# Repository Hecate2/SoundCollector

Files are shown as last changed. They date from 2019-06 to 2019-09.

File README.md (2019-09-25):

# SoundCollector
录音电路。这是一个课程项目，需要±12V和+5V同时供电，因此没有实用价值。该电路用OP07CP做两级反向放大器和一级加法器。
用IAP15F2K61S2单片机采样，并用串口发送至电脑。
保存数据为bin文件后，用MATLAB播放。有两阶RC无源低通滤波（虽然这一步并没有实际意义）。
受限于串口的传输速率（最高波特率115200），无法保留高频的成分。

我已经用实际硬件调试成功。用MATLAB运行play.m即可播放sound.bin录音结果。
需要STC公司的软件stc-isp-15xx-v6.86q.exe来烧录单片机程序。其中的串口助手还可收取串口传来的录音数据。

stcmcu_altium_lib.IntLib由STC制作，含STC各种单片机的原理图，封装，footprint，用于Altium Designer设计PCB。

Mic.PrjPcb是实际电路图的PCB设计项目。最终采用的PCB设计是Mic2.PcbDoc。这个板子的纵向高度正好能装进淘宝上的8格塑料盒子，横向宽度也可以再缩一缩。可变电阻用VR5封装，可调节放大倍数和加法器。**原理图Mic.SchDoc把OP07CP的+12V和-12V供电画反了，但PCB上标注的+12V和-12V是正确的。**MAX232CPE和串口端可以用USB转串口的单片机编程器代替。淘宝上不到十块钱，可靠性绝佳。退耦电容C99，C100，C101完全可以不焊，反正是专门的直流电源和电脑主板供电。**电容C0的电压是下面比上面高（或者说靠近单片机的一侧电压比较高）。千万不要焊反了。**
MicOP07CP.ms14是模拟电路的仿真。可用Multisim 14打开。

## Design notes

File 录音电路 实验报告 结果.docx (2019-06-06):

6、 实验结果
  a) 不播放音乐时的模拟输出

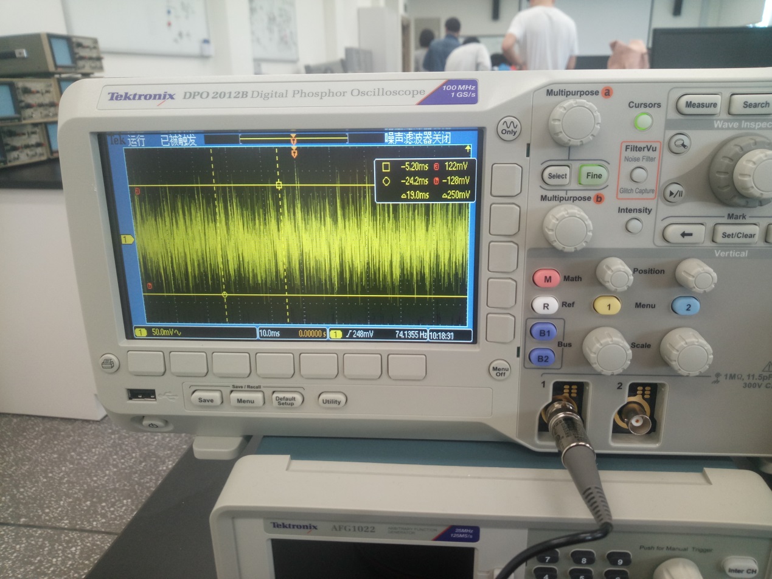
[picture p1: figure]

进行这一试验是为了测试模拟输出的底噪。测试环境并没有完全静音。可认为底噪幅度小于128mV。

  b) 模拟音频信噪比

假设模拟音频平均幅值2V，则信噪比大于10log10((2/0.128)²)= 23.8764 dB

  c) 录音结果（已经数字化）

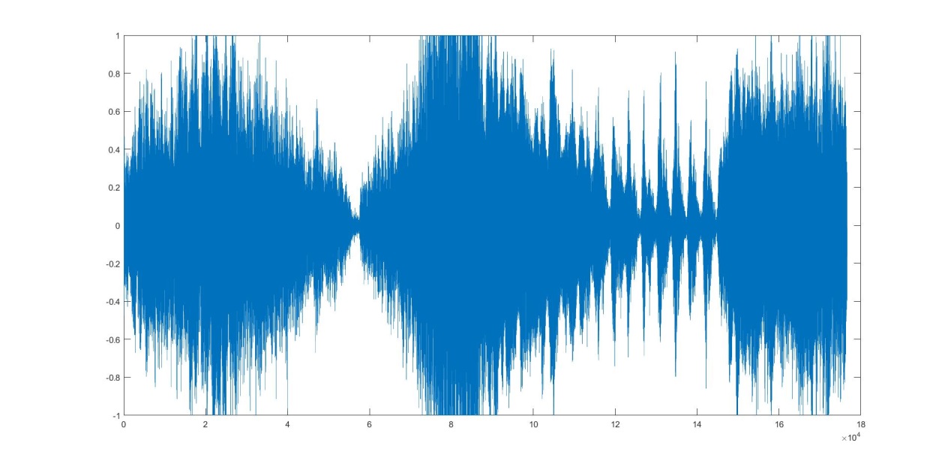
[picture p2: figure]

由于播放音乐音量过大，电压有时会超出采样范围。可调节放大倍数阻止这一现象。

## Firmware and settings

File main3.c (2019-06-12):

#include <stc15fxxxx.h> //调用stc15f系列头文件,下载地址: http://pan.baidu.com/s/1eRUbjLS

//串口部分-----------------------------------------------------------------------------------------------------------------------------------------------------------------------------------

/*************常量定义****************/


#define MAIN_Fosc 22118400L //主时钟,晶振频率不同的直接在这里修改频率
#define serial_one_read_max 32 //定义缓存区的长度
#define serial_one_baud_rate 115200L //波特率,只需在这里修改波特率就可以了
#define Timer1_Reload (65536UL -(MAIN_Fosc / 4 / serial_one_baud_rate))  //用定时器1做波特率发生器，计算定时器1的重装值 


/*************变量定义****************/
u8 serial_one_read_data[serial_one_read_max]; //定义串口接受数据缓存区
u8 serial_one_read_count=0; //接受数据的个数


//初始化串口1
void serial_one_init()
{
SCON |= 0x40; //8位数据
P_SW1 &= ~0xc0; //UART1 使用P30 P31口 默认
TR1 = 0; //关闭定时器
AUXR &= ~0x01; //S1 BRT Use Timer1;
TMOD &= ~(1<<6); //Timer1 set As Timer
TMOD &= ~0x30; //Timer1_16bitAutoReload;2
AUXR |= (1<<6); //Timer1 set as 1T mode
TH1 = (u8)(Timer1_Reload >> 8);
TL1 = (u8)Timer1_Reload;
TR1 = 1; //打开定时器
PS = 1; //高优先级中断
REN = 1; //允许接收
ES = 1; //允许中断


EA = 1; //允许全局中断
}


//延时10毫秒
void Delay10ms() //@22.1184MHz
{
unsigned char i, j, k;


_nop_();
_nop_();
i = 1;
j = 216;
k = 35;
do
{
do
{
while (--k);
} while (--j);
} while (--i);
}


//串口1发送一个字节
void serial_one_send_byte(u8 dat)
{
SBUF = dat;//发送数据
while(!TI);//等待发送完毕
TI=0; //清除发送标志
}


//串口1发送字符串
void serial_one_send_string(u8 *dat)
{
while(*dat)
serial_one_send_byte(*dat++);
}


//串口1发送指定指定长度数据
void serial_one_send_length_string(u8 *dat,u8 length)
{
u8 i=0;
for(;i < length;i++)
serial_one_send_byte(dat[i]);
}

/********************* 串口1中断函数************************/
void UART1_int (void) interrupt UART1_VECTOR
{
if(RI)
{
RI = 0;//清除接受标志
serial_one_read_data[serial_one_read_count] = SBUF;//将数据存入数组
if(++serial_one_read_count > serial_one_read_max) //避免溢出
serial_one_read_count = 0;
}


// if(TI)
// {
// }
}


//ADC部分----------------------------------------------------------------------------------------------------------------------------------------------------

//#include "reg51.h"
//#include "intrins.h"

#define FOSC    11059200L
#define BAUD    9600

typedef unsigned char BYTE;
typedef unsigned int WORD;

#define     URMD    0           //0:使用定时器2作为波特率发生器
                                //1:使用定时器1的模式0(16位自动重载模式)作为波特率发生器
                                //2:使用定时器1的模式2(8位自动重载模式)作为波特率发生器

#define ADC_POWER   0x80            //ADC电源控制位
#define ADC_FLAG    0x10            //ADC完成标志
#define ADC_START   0x08            //ADC起始控制位
#define ADC_SPEEDLL 0x00            //540个时钟
#define ADC_SPEEDL  0x20            //360个时钟
#define ADC_SPEEDH  0x40            //180个时钟
#define ADC_SPEEDHH 0x60            //90个时钟

void InitUart();
void InitADC();
void SendData(BYTE dat);
BYTE GetADCResult(BYTE ch);
void Delay(WORD n);
void ShowResult(BYTE ch);

void main()
{
    P0M0 = 0x00;
    P0M1 = 0x00;
    P1M0 = 0x00;
    P1M1 = 0x00;
    P2M0 = 0x00;
    P2M1 = 0x00;
    P3M0 = 0x00;
    P3M1 = 0x00;
    P4M0 = 0x00;
    P4M1 = 0x00;
    P5M0 = 0x00;
    P5M1 = 0x00;
    P6M0 = 0x00;
    P6M1 = 0x00;
    P7M0 = 0x00;
    P7M1 = 0x00;

Delay10ms();//延时10毫秒
Delay10ms();//延时10毫秒
serial_one_init();//串口初始化

//if(serial_one_read_count > 0)//如果接受到数据
//{
//Delay10ms();//延时10毫秒，等待数据全部读入
//serial_one_send_length_string(serial_one_read_data,serial_one_read_count);//发送接收到的数据
//serial_one_read_count = 0;//接收计数清0
//}

    InitADC();                      //初始化ADC
    while (1)
    {
        //ShowResult(0);              //显示通道0
        //ShowResult(1);              //显示通道1
        //ShowResult(2);              //显示通道2
        //ShowResult(3);              //显示通道3
        //ShowResult(4);              //显示通道4
        //ShowResult(5);              //显示通道5
        //ShowResult(6);              //显示通道6
        //ShowResult(7);              //显示通道7
			u8 dat=GetADCResult(7);
			serial_one_send_length_string(&dat,1);
    }
}

/*----------------------------
读取ADC结果
----------------------------*/
BYTE GetADCResult(BYTE ch)
{
    ADC_CONTR = ADC_POWER | ADC_SPEEDLL | ch | ADC_START;
    _nop_();                        //等待4个NOP
    _nop_();
    _nop_();
    _nop_();
    while (!(ADC_CONTR & ADC_FLAG));//等待ADC转换完成
    ADC_CONTR &= ~ADC_FLAG;         //Close ADC

    return ADC_RES;                 //返回ADC结果
}

/*----------------------------
初始化ADC
----------------------------*/
void InitADC()
{
    P1ASF = 0xff;                   //设置P1口为AD口
    ADC_RES = 0;                    //清除结果寄存器
    ADC_CONTR = ADC_POWER | ADC_SPEEDLL;
    Delay(2);                       //ADC上电并延时
}


/*----------------------------
软件延时
----------------------------*/
void Delay(WORD n)
{
    WORD x;

    while (n--)
    {
        x = 5000;
        while (x--);
    }
}

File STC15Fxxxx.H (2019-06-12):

#ifndef	_STC15Fxxxx_H
#define	_STC15Fxxxx_H

#include <intrins.h>

/*  BYTE Registers  */
sfr P0   = 0x80;
sfr SP   = 0x81;
sfr DPL  = 0x82;
sfr DPH  = 0x83;
sfr	S4CON = 0x84;
sfr	S4BUF = 0x85;
sfr PCON = 0x87;

sfr TCON = 0x88;
sfr TMOD = 0x89;
sfr TL0  = 0x8A;
sfr TL1  = 0x8B;
sfr TH0  = 0x8C;
sfr TH1  = 0x8D;
sfr	AUXR = 0x8E;
sfr WAKE_CLKO = 0x8F;
sfr INT_CLKO = 0x8F;
sfr	AUXR2    = 0x8F;

sfr RL_TL0  = 0x8A;
sfr RL_TL1  = 0x8B;
sfr RL_TH0  = 0x8C;
sfr RL_TH1  = 0x8D;


sfr P1   = 0x90;
sfr P1M1 = 0x91;	//P1M1.n,P1M0.n 	=00--->Standard,	01--->push-pull		实际上1T的都一样
sfr P1M0 = 0x92;	//					=10--->pure input,	11--->open drain
sfr P0M1 = 0x93;	//P0M1.n,P0M0.n 	=00--->Standard,	01--->push-pull
sfr P0M0 = 0x94;	//					=10--->pure input,	11--->open drain
sfr P2M1 = 0x95;	//P2M1.n,P2M0.n 	=00--->Standard,	01--->push-pull
sfr P2M0 = 0x96;	//					=10--->pure input,	11--->open drain
sfr CLK_DIV = 0x97;
sfr PCON2   = 0x97;

sfr SCON  = 0x98;
sfr SBUF  = 0x99;
sfr S2CON = 0x9A;	//
sfr S2BUF = 0x9B;	//
sfr P1ASF = 0x9D;	//只写，模拟输入(AD或LVD)选择

sfr P2    = 0xA0;
sfr BUS_SPEED = 0xA1;
sfr AUXR1 = 0xA2;
sfr P_SW1 = 0xA2;

sfr IE    = 0xA8;
sfr SADDR = 0xA9;
sfr WKTCL = 0xAA;	//唤醒定时器低字节
sfr WKTCH = 0xAB;	//唤醒定时器高字节
sfr	S3CON = 0xAC;
sfr S3BUF = 0xAD;
sfr IE2   = 0xAF;	//STC12C5A60S2系列

sfr P3    = 0xB0;
sfr P3M1  = 0xB1;	//P3M1.n,P3M0.n 	=00--->Standard,	01--->push-pull
sfr P3M0  = 0xB2;	//					=10--->pure input,	11--->open drain
sfr P4M1  = 0xB3;	//P4M1.n,P4M0.n 	=00--->Standard,	01--->push-pull
sfr P4M0  = 0xB4;	//					=10--->pure input,	11--->open drain
sfr IP2   = 0xB5;	//STC12C5A60S2系列
sfr IPH2  = 0xB6;	//STC12C5A60S2系列
sfr IPH   = 0xB7;

sfr IP        = 0xB8;
sfr SADEN     = 0xB9;
sfr	P_SW2     = 0xBA;
sfr ADC_CONTR = 0xBC;	//带AD系列
sfr ADC_RES   = 0xBD;	//带AD系列
sfr ADC_RESL  = 0xBE;	//带AD系列

sfr P4        = 0xC0;
sfr WDT_CONTR = 0xC1;
sfr IAP_DATA  = 0xC2;
sfr IAP_ADDRH = 0xC3;
sfr IAP_ADDRL = 0xC4;
sfr IAP_CMD   = 0xC5;
sfr IAP_TRIG  = 0xC6;
sfr IAP_CONTR = 0xC7;

sfr ISP_DATA  = 0xC2;
sfr ISP_ADDRH = 0xC3;
sfr ISP_ADDRL = 0xC4;
sfr ISP_CMD   = 0xC5;
sfr ISP_TRIG  = 0xC6;
sfr ISP_CONTR = 0xC7;

sfr P5     = 0xC8;	//
sfr P5M1   = 0xC9;	//	P5M1.n,P5M0.n 	=00--->Standard,	01--->push-pull
sfr P5M0   = 0xCA;	//					=10--->pure input,	11--->open drain
sfr P6M1   = 0xCB;	//	P5M1.n,P5M0.n 	=00--->Standard,	01--->push-pull
sfr P6M0   = 0xCC;	//					=10--->pure input,	11--->open drain
sfr SPSTAT = 0xCD;	//
sfr SPCTL  = 0xCE;	//
sfr SPDAT  = 0xCF;	//

sfr PSW  = 0xD0;
sfr	T4T3M = 0xD1;
sfr	T4H  = 0xD2;
sfr	T4L  = 0xD3;
sfr	T3H  = 0xD4;
sfr	T3L  = 0xD5;
sfr	T2H  = 0xD6;
sfr	T2L  = 0xD7;

sfr	TH4  = 0xD2;
sfr	TL4  = 0xD3;
sfr	TH3  = 0xD4;
sfr	TL3  = 0xD5;
sfr	TH2  = 0xD6;
sfr	TL2  = 0xD7;

sfr	RL_T4H  = 0xD2;
sfr	RL_T4L  = 0xD3;
sfr	RL_T3H  = 0xD4;
sfr	RL_T3L  = 0xD5;
sfr	RL_T2H  = 0xD6;
sfr	RL_T2L  = 0xD7;

sfr CCON = 0xD8;	//
sfr CMOD = 0xD9;	//
sfr CCAPM0 = 0xDA;	//PCA模块0的工作模式寄存器。
sfr CCAPM1 = 0xDB;	//PCA模块1的工作模式寄存器。
sfr CCAPM2 = 0xDC;	//PCA模块2的工作模式寄存器。

sfr ACC    = 0xE0;
sfr	P7M1   = 0xE1;
sfr	P7M0   = 0xE2;

sfr	P6     = 0xE8;
sfr CL     = 0xE9;	//
sfr CCAP0L = 0xEA;	//PCA模块0的捕捉/比较寄存器低8位。
sfr CCAP1L = 0xEB;	//PCA模块1的捕捉/比较寄存器低8位。
sfr CCAP2L = 0xEC;	//PCA模块2的捕捉/比较寄存器低8位。

sfr B      = 0xF0;
sfr PCA_PWM0 = 0xF2;	//PCA模块0 PWM寄存器。
sfr PCA_PWM1 = 0xF3;	//PCA模块1 PWM寄存器。
sfr PCA_PWM2 = 0xF4;	//PCA模块2 PWM寄存器。

sfr	P7     = 0xF8;
sfr CH     = 0xF9;
sfr CCAP0H = 0xFA;		//PCA模块0的捕捉/比较寄存器高8位。
sfr CCAP1H = 0xFB;		//PCA模块1的捕捉/比较寄存器高8位。
sfr CCAP2H = 0xFC;		//PCA模块2的捕捉/比较寄存器高8位。


/*  BIT Registers  */
/*  PSW   */
sbit CY   = PSW^7;
sbit AC   = PSW^6;
sbit F0   = PSW^5;
sbit RS1  = PSW^4;
sbit RS0  = PSW^3;
sbit OV   = PSW^2;
sbit F1   = PSW^1;
sbit P    = PSW^0;

/*  TCON  */
sbit TF1  = TCON^7;	//定时器1溢出中断标志位
sbit TR1  = TCON^6;	//定时器1运行控制位
sbit TF0  = TCON^5;	//定时器0溢出中断标志位
sbit TR0  = TCON^4;	//定时器0运行控制位
sbit IE1  = TCON^3;	//外中断1标志位
sbit IT1  = TCON^2;	//外中断1信号方式控制位，1：下降沿中断，0：上升下降均中断。
sbit IE0  = TCON^1;	//外中断0标志位
sbit IT0  = TCON^0;	//外中断0信号方式控制位，1：下降沿中断，0：上升下降均中断。

/*  P0  */
sbit  P00 = P0^0;
sbit  P01 = P0^1;
sbit  P02 = P0^2;
sbit  P03 = P0^3;
sbit  P04 = P0^4;
sbit  P05 = P0^5;
sbit  P06 = P0^6;
sbit  P07 = P0^7;

/*  P1  */
sbit  P10 = P1^0;
sbit  P11 = P1^1;
sbit  P12 = P1^2;
sbit  P13 = P1^3;
sbit  P14 = P1^4;
sbit  P15 = P1^5;
sbit  P16 = P1^6;
sbit  P17 = P1^7;

sbit  RXD2      = P1^0;
sbit  TXD2      = P1^1;
sbit  CCP1      = P1^0;
sbit  CCP0      = P1^1;
sbit  SPI_SS    = P1^2;
sbit  SPI_MOSI  = P1^3;
sbit  SPI_MISO  = P1^4;
sbit  SPI_SCLK  = P1^5;

sbit  SPI_SS_2    = P2^4;
sbit  SPI_MOSI_2  = P2^3;
sbit  SPI_MISO_2  = P2^2;
sbit  SPI_SCLK_2  = P2^1;

sbit  SPI_SS_3    = P5^4;
sbit  SPI_MOSI_3  = P4^0;
sbit  SPI_MISO_3  = P4^1;
sbit  SPI_SCLK_3  = P4^3;

/*  P2  */
sbit  P20 = P2^0;
sbit  P21 = P2^1;
sbit  P22 = P2^2;
sbit  P23 = P2^3;
sbit  P24 = P2^4;
sbit  P25 = P2^5;
sbit  P26 = P2^6;
sbit  P27 = P2^7;

/*  P3  */
sbit  P30 = P3^0;
sbit  P31 = P3^1;
sbit  P32 = P3^2;
sbit  P33 = P3^3;
sbit  P34 = P3^4;
sbit  P35 = P3^5;
sbit  P36 = P3^6;
sbit  P37 = P3^7;

sbit RXD  = P3^0;
sbit TXD  = P3^1;
sbit INT0 = P3^2;
sbit INT1 = P3^3;
sbit T0   = P3^4;
sbit T1   = P3^5;
sbit WR   = P3^6;
sbit RD   = P3^7;
sbit CCP2  = P3^7;

sbit CLKOUT0   = P3^5;
sbit CLKOUT1   = P3^4;

/*  P4  */
sbit  P40 = P4^0;
sbit  P41 = P4^1;
sbit  P42 = P4^2;
sbit  P43 = P4^3;
sbit  P44 = P4^4;
sbit  P45 = P4^5;
sbit  P46 = P4^6;
sbit  P47 = P4^7;

/*  P5  */
sbit  P50 = P5^0;
sbit  P51 = P5^1;
sbit  P52 = P5^2;
sbit  P53 = P5^3;
sbit  P54 = P5^4;
sbit  P55 = P5^5;
sbit  P56 = P5^6;
sbit  P57 = P5^7;

/*  SCON  */
sbit SM0  = SCON^7;	//SM0/FE		SM0 SM1 = 00 ~ 11: 方式0~3
sbit SM1  = SCON^6;	//
sbit SM2  = SCON^5;	//多机通讯
sbit REN  = SCON^4;	//接收允许
sbit TB8  = SCON^3;	//发送数据第8位
sbit RB8  = SCON^2;	//接收数据第8位
sbit TI   = SCON^1;	//发送中断标志位
sbit RI   = SCON^0;	//接收中断标志位

/*  IE   */
sbit EA   = IE^7;	//中断允许总控制位
sbit ELVD = IE^6;	//低压监测中断允许位
sbit EADC = IE^5;	//ADC 中断 允许位
sbit ES   = IE^4;	//串行中断 允许控制位
sbit ET1  = IE^3;	//定时中断1允许控制位
sbit EX1  = IE^2;	//外部中断1允许控制位
sbit ET0  = IE^1;	//定时中断0允许控制位
sbit EX0  = IE^0;	//外部中断0允许控制位


/*  IP   */ 
/*
sbit PPCA = IP^7;	//PCA 中断 优先级设定位
sbit PLVD = IP^6; 	//低压中断 优先级设定位
sbit PADC = IP^5; 	//ADC 中断 优先级设定位
sbit PS   = IP^4;	//串行中断0优先级设定位
sbit PT1  = IP^3;	//定时中断1优先级设定位
sbit PX1  = IP^2;	//外部中断1优先级设定位
sbit PT0  = IP^1;	//定时中断0优先级设定位
sbit PX0  = IP^0;	//外部中断0优先级设定位
*/

sbit ACC0 = ACC^0;
sbit ACC1 = ACC^1;
sbit ACC2 = ACC^2;
sbit ACC3 = ACC^3;
sbit ACC4 = ACC^4;
sbit ACC5 = ACC^5;
sbit ACC6 = ACC^6;
sbit ACC7 = ACC^7;

sbit B0 = B^0;
sbit B1 = B^1;
sbit B2 = B^2;
sbit B3 = B^3;
sbit B4 = B^4;
sbit B5 = B^5;
sbit B6 = B^6;
sbit B7 = B^7;
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

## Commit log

2019-06-06 底噪测量；录音波形
2019-06-06 底噪测量；波形图片
2019-06-12 单片机IAP15F2K61S2程序
